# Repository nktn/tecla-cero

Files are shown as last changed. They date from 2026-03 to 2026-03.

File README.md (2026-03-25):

# TECLA-CERO(セロ)
シンプルなロータス配列の乾電池・トラボ付き無線分割キーボードです。
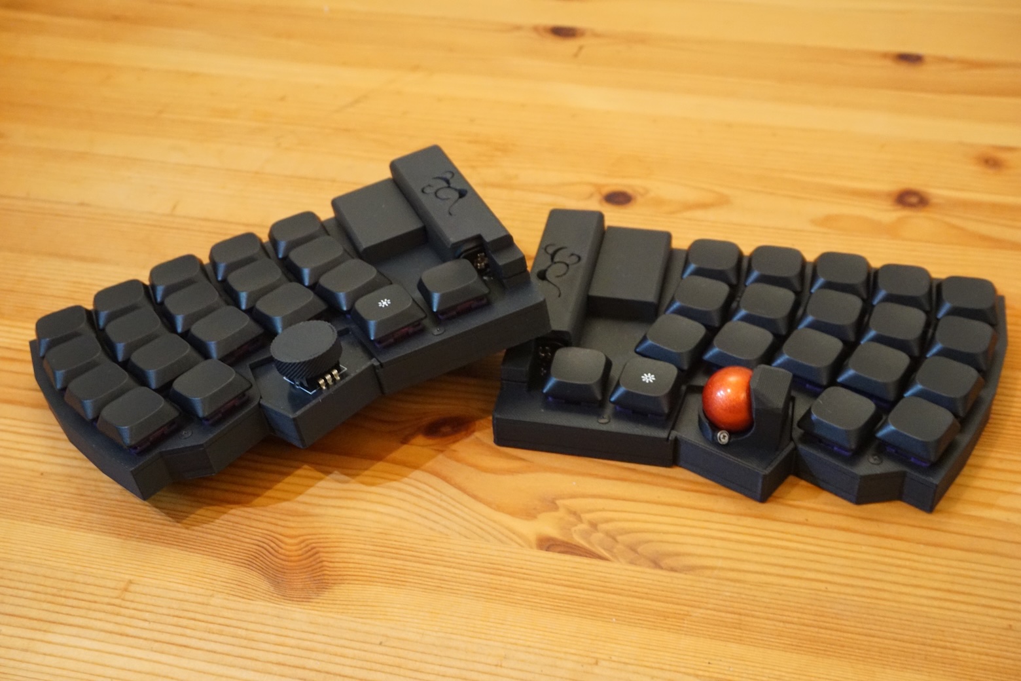
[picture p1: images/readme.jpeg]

## 特徴
- ロータス配列
- 38キー
- 左側にロータリーエンコーダー
- 右側にトラックボール（PAW3222）
- BMP Boost使用
- BLE/USB両対応
- keymap-editor / ZMK Studio対応 

## ビルドガイド
- [こちら](https://github.com/nktn/tecla-cero/blob/main/docs/buildguide_proto.md)を参考に進めてください

## 注意
- ソケット、ロータリーエンコーダー、電池ボックスのはんだ付けが必要です。
- ケースが3Dプリントでの確認しかできておりません

## 謝辞
本プロジェクトの設計は[torabo-tsuki-lp](https://github.com/sekigon-gonnoc/torabo-tsuki-lp) を参考にさせていただきました。

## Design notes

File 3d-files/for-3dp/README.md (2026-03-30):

# TECLA-CERO(セロ)の３Dプリント印刷設定例
キーケット2026に展示していたキーボードを作る際に設定したプリント設定を参考情報として記載させていただきます。

# 3Dプリントの機種
BambuLab A1 mini

# ビルドプレート
* テクスチャPEIプレート（A1 mini購入時のもの）
* (ノブ/トラックボールケース) スムースPEIビルドプレート

# フィラメント
PLA Matte(Black)

# Bambu Studio設定
バージョン：2.5.0.66  
システムプリセット： 0.20mm Standard @BBL A1M  
フィラメント設定など：デフォルト(変更なし)

# Stepファイルの読み込み設定
デフォルト  
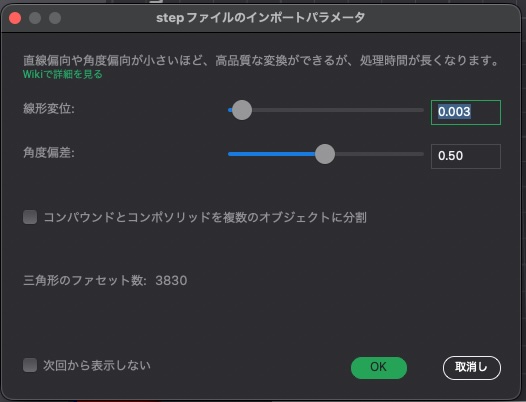
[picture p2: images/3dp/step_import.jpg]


# 各種設定について
左右に関して基本的には同じ設定をしています。(そして試行錯誤していたので1プレート1オブジェクトで印刷しておりました・・・ので印刷される際には複数配置などしてください)

## サポート有効化（パラメータはデフォルト）の設定
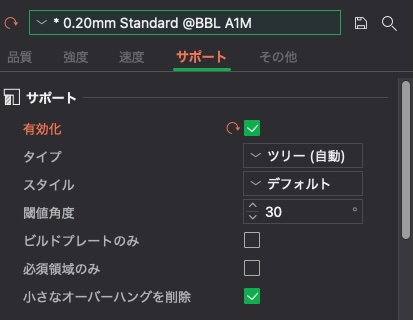
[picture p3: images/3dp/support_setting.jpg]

# Topプレート
サポート：有効化（パラメータはデフォルト）  
配置向き：マグネットを入れる口が上向きになるように配置してください。  
備考：今回は反ることがなかったのでブリムはつけておりません。必要に応じてセットしてください。
## 配置
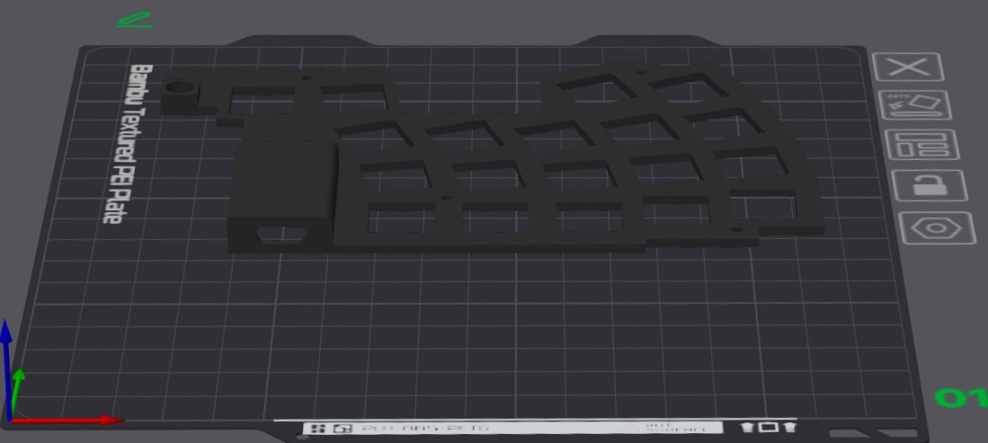
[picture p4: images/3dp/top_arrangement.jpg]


# 電池ケース
サポート：有効化（パラメータはデフォルト）  
配置向き：マグネットを入れる口が下向きになるように配置してください  
サポート編集：薄い部分と底面から離れている部分にサポートが有効になるように色付けしてください（私のは適当でちょっと恥ずかしいのですが。。。）

## 配置
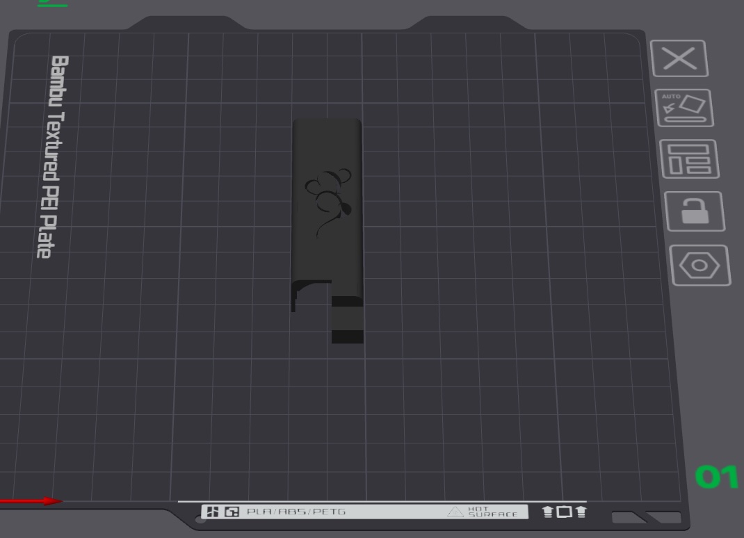
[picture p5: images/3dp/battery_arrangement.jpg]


## サポート編集：薄い部分
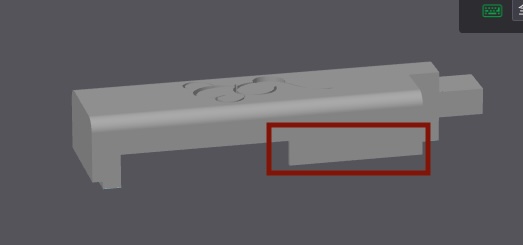
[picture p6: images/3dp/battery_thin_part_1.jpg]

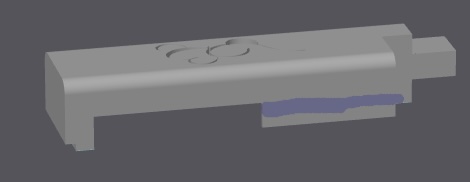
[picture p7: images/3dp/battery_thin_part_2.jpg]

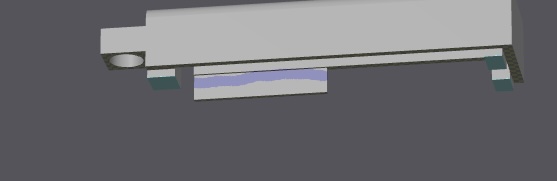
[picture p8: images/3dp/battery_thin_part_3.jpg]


## サポート編集：底面から離れている部分
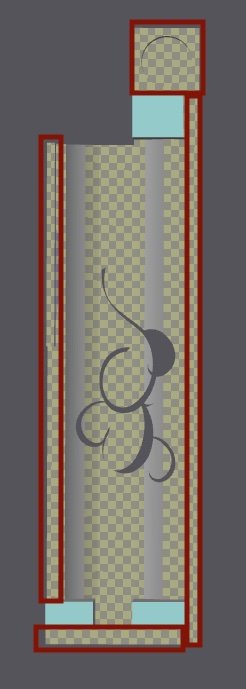
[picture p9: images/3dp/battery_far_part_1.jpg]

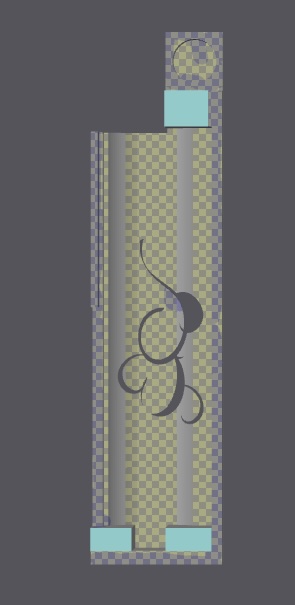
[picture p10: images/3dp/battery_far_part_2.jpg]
   
※わかりにくいですが薄い紫色がついているところです

## プレビュー
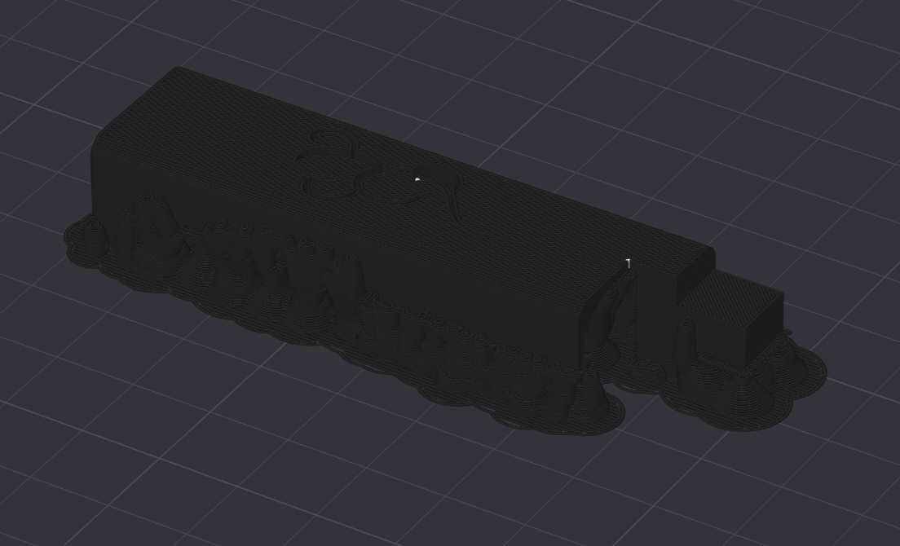
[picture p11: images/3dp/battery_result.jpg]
  

# ボトムケース
サポート：有効化（ブリムの関係？自動的についている）  
配置向き：底面が下になるように配置してください。  
マウス耳型ブリム：角全てに設定（親の仇かという感じで付けてました）  
ベッド接着：ブリムタイプ塗装済み  
備考：反ってしまう場合は洗濯ノリを使ってプリントするといいですよと聞きましてご自身の責任でお試しください。[参考記事](https://note.com/jinsato_tech/n/n6989bb54e91c)

## 配置
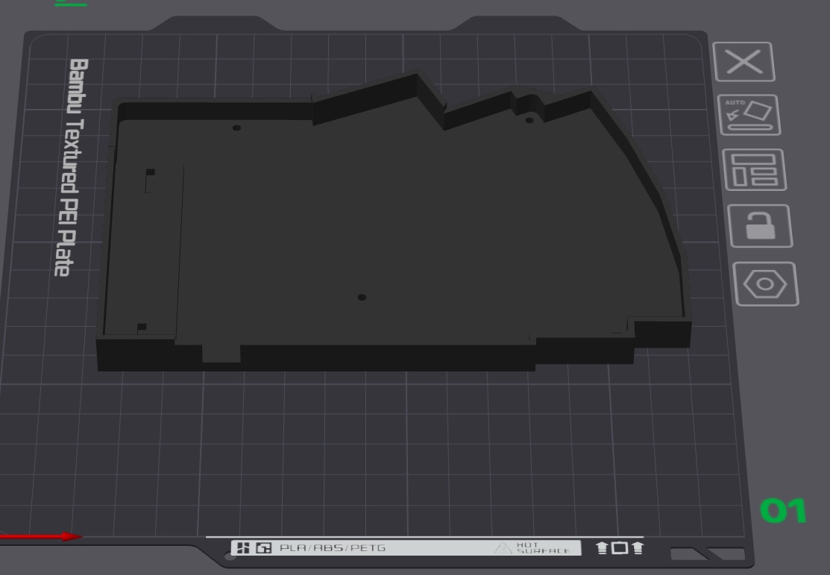
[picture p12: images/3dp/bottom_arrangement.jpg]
  

## ブリム
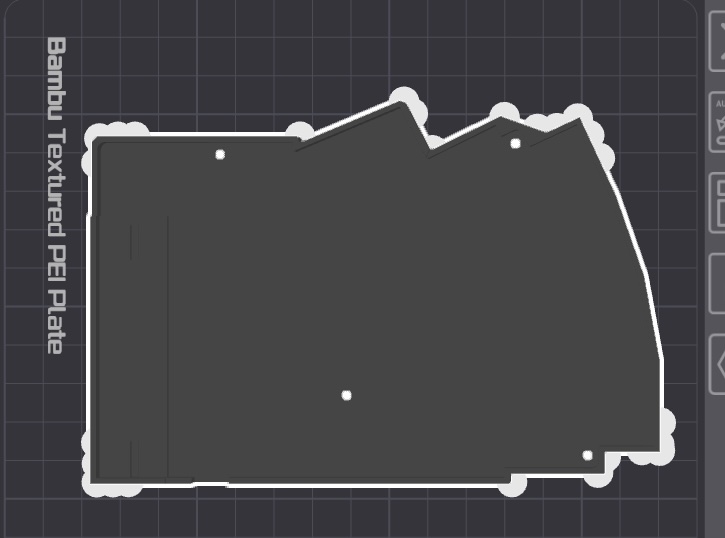
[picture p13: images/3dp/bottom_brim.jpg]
  

### ブリム設定
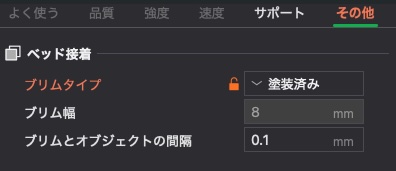
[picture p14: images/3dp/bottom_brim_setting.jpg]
 

## プレビュー
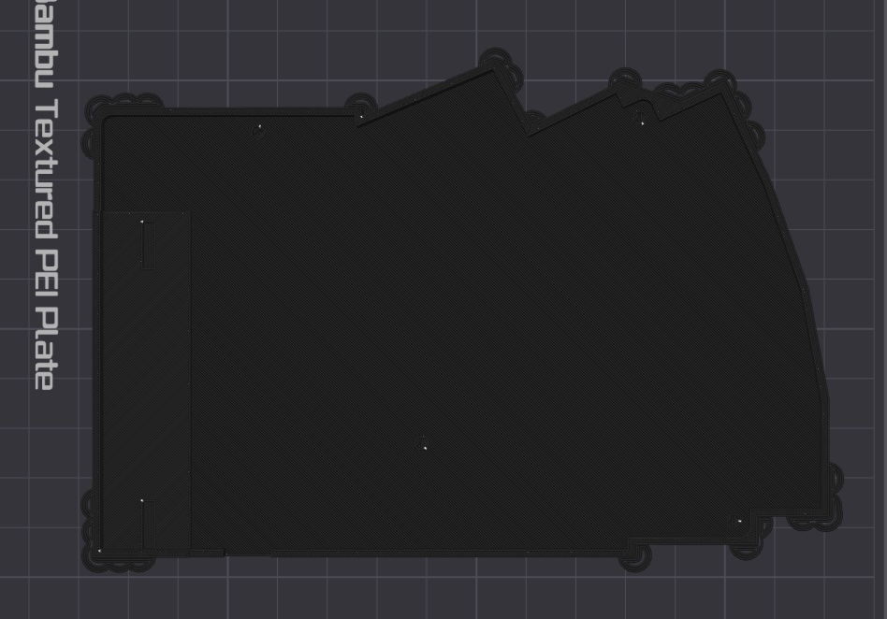
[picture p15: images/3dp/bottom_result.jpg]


# ノブ
配置向き：ノブに刺す穴を上になるように配置してください

## 配置
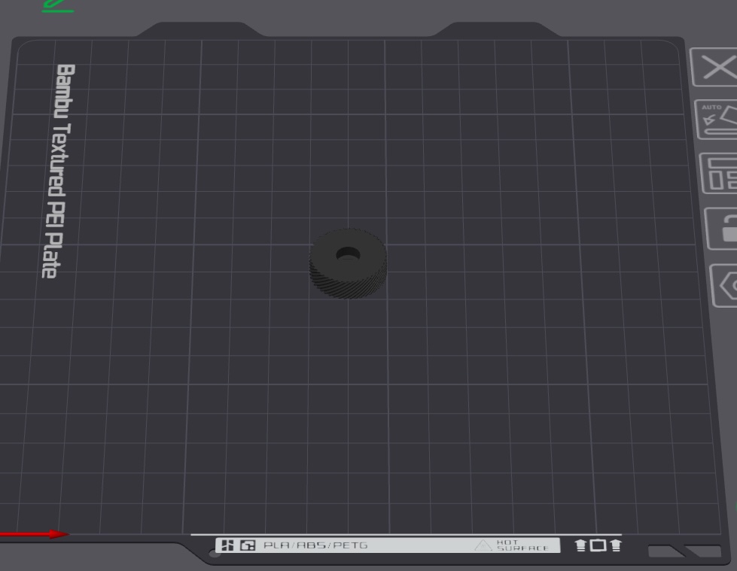
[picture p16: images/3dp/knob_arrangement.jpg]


# 一体型トラックボールケース
サポート：有効化（パラメータはデフォルト）  
配置向き：トラックボールを奥側を上に配置してください  
座標：Zを8度回転
## 配置
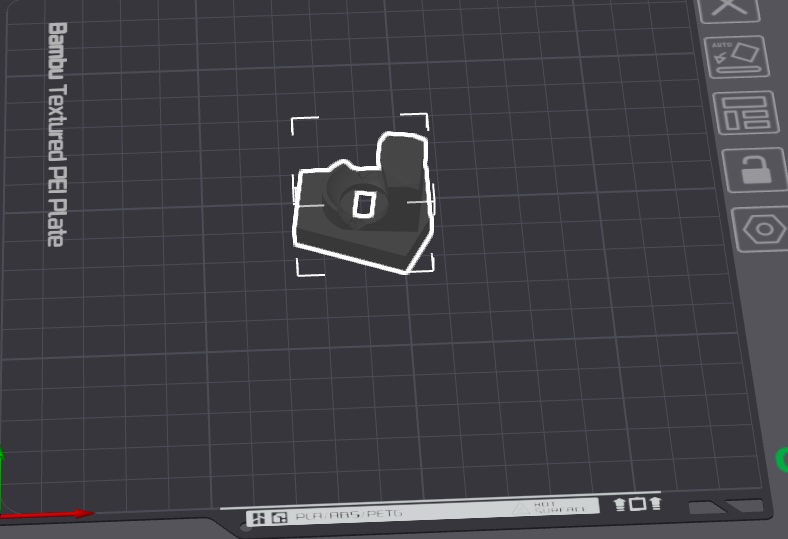
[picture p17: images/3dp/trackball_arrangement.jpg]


## 座標
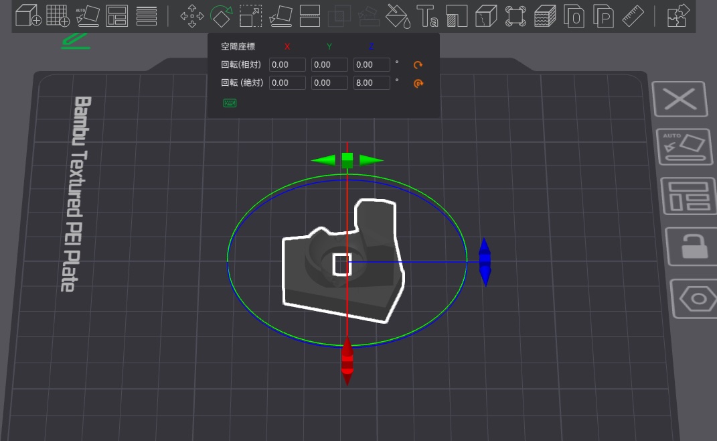
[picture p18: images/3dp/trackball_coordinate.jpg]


## プレビュー
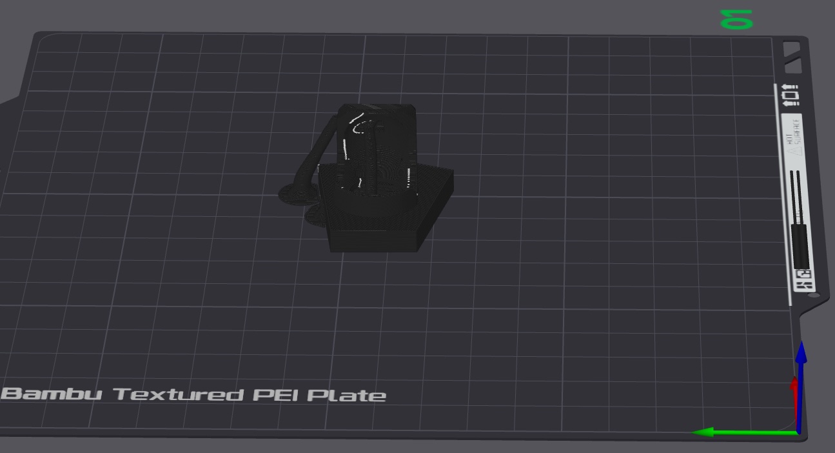
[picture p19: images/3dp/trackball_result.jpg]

※わかりにくいですがサポートが設定されている状態

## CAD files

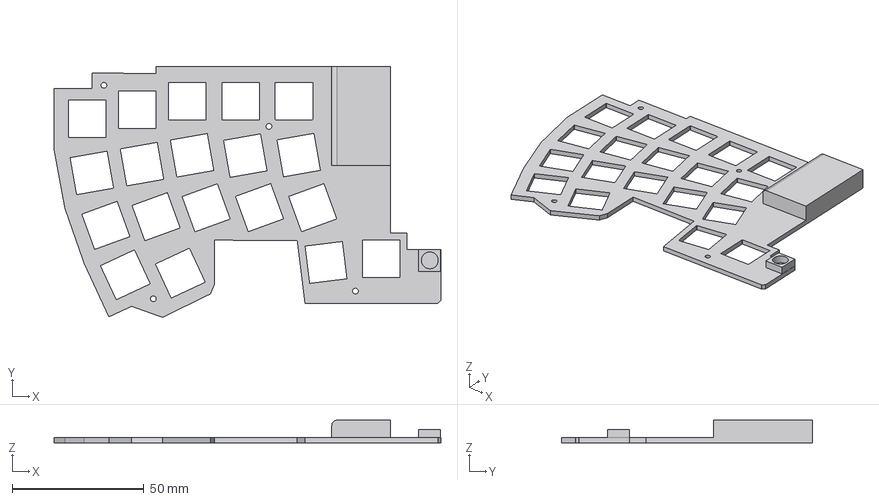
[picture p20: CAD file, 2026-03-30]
3d-files/for-3dp/left_top.step
146.7 x 95.1 x 8.60 mm
case-19mm-3-Body.step
フォルダー 18
acanthus_tall_bigleaf
left-B_Mask
right-User_Drawings
right-Edge_Cuts
left-Edge_Cuts_v2
mesh_large
mesh_for_shapr3d
controller-cover-aa-Body.step
left-F_Mask
left-B_Silkscreen
left-Edge_Cuts
left-F_Silkscreen
left-User_1

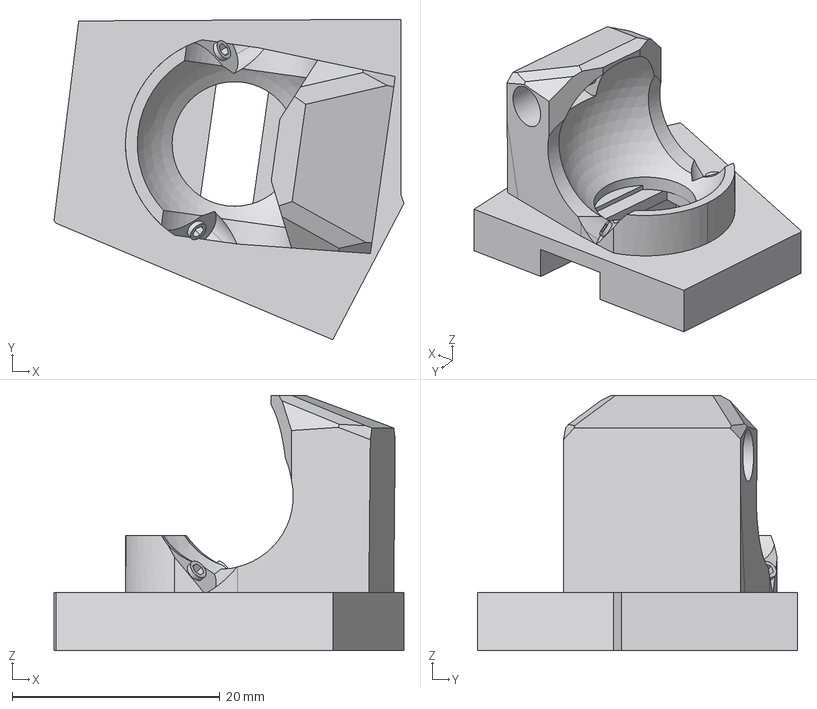
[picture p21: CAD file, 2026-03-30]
3d-files/for-3dp/right_trackball_case.step
33.7 x 30.9 x 24.6 mm
case-19mm-3-Body.step
フォルダー 18
acanthus_tall_bigleaf
left-B_Mask
right-User_Drawings
right-Edge_Cuts
left-Edge_Cuts_v2
mesh_large
mesh_for_shapr3d
controller-cover-aa-Body.step
left-F_Mask
left-B_Silkscreen
left-Edge_Cuts
left-F_Silkscreen
left-User_1

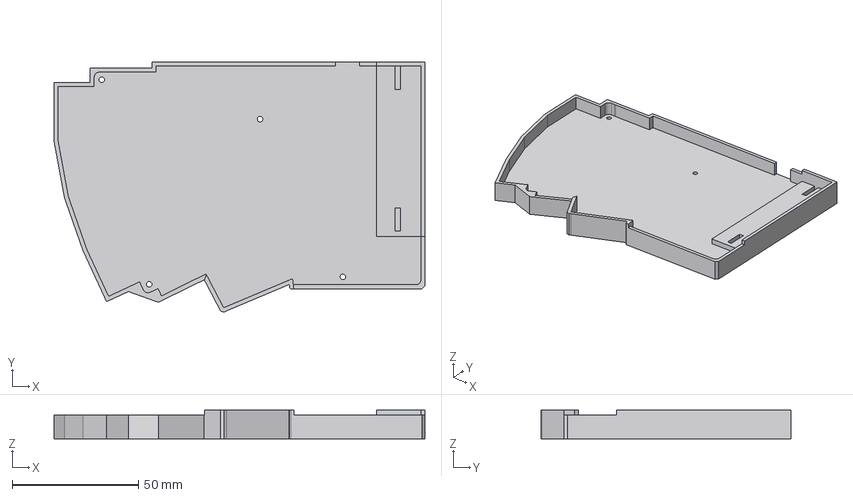
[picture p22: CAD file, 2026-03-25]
3d-files/for-3dp/left_bottom.step
146.8 x 99.0 x 11.4 mm
case-19mm-3-Body.step
left-B_Mask
right-User_Drawings
right-Edge_Cuts
left-Edge_Cuts_v2
mesh_large
mesh_for_shapr3d
controller-cover-aa-Body.step
left-F_Mask
left-B_Silkscreen
left-Edge_Cuts
left-F_Silkscreen
left-User_1

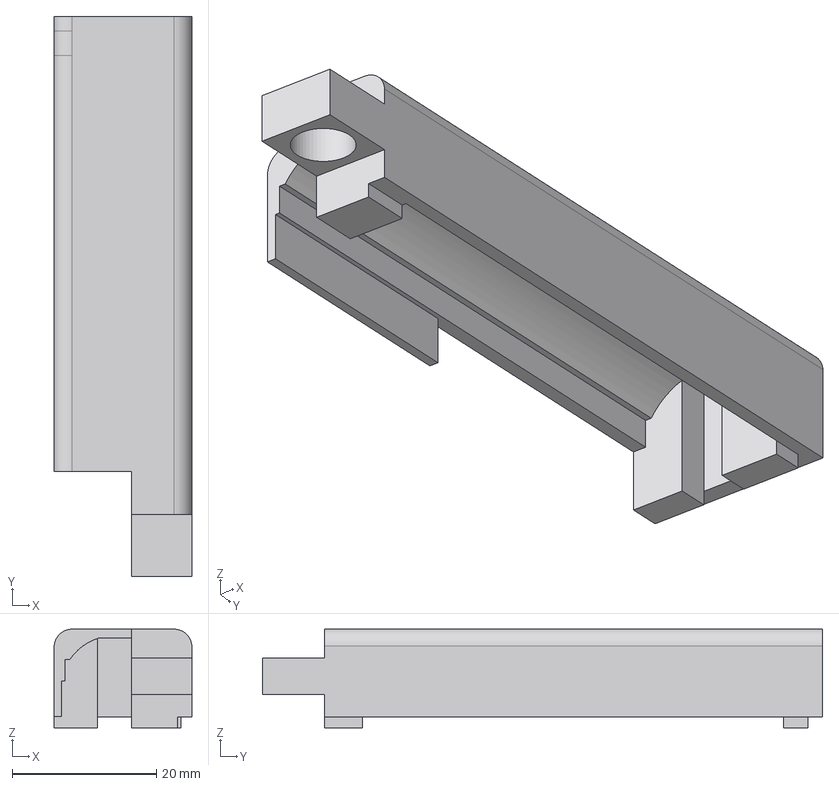
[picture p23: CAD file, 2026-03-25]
3d-files/for-3dp/left_battery_case.step
19.1 x 77.7 x 13.7 mm
case-19mm-3-Body.step
left-B_Mask
right-User_Drawings
right-Edge_Cuts
left-Edge_Cuts_v2
mesh_large
mesh_for_shapr3d
controller-cover-aa-Body.step
left-F_Mask
left-B_Silkscreen
left-Edge_Cuts
left-F_Silkscreen
left-User_1

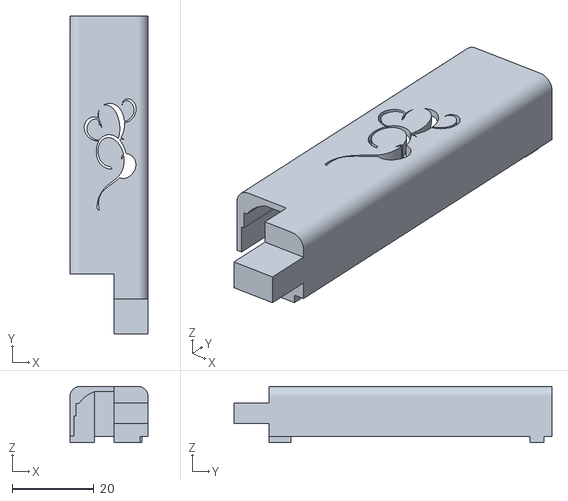
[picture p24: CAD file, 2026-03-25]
3d-files/for-3dp/left_battery_designed_case.stl
19.1 x 77.7 x 13.7

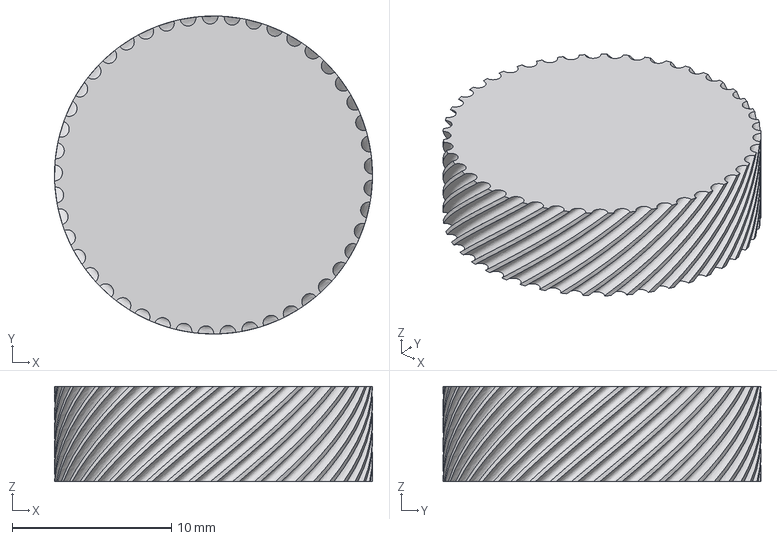
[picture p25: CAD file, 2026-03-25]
3d-files/for-3dp/left_knob.step
20.0 x 20.0 x 6.00 mm

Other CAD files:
3d-files/for-3dp/right_top.step
3d-files/for-3dp/right_battery_designed_case.stl
3d-files/for-3dp/right_battery_case.step
3d-files/for-3dp/right_bottom.step

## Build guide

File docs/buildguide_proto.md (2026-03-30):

# Build Guide for TECLA-CERO

こちらはTECLA-CEROのビルドガイドです。  
**はんだ付けが必要です**

また、プロトタイプということでケースが**3Dプリンターでの印刷**確認しかできておりません。

## プロト販売の同梱品
| 名称 | 数  |備考| 
|:-|:-|:-|
| プロトタイプメイン基板(PCBAで半組み立て済み) | 1 | プロト版として部品番号がプリントされたデザインです　|
| 電池ボックス(単三) | 2 |入手先：[秋月電子](https://akizukidenshi.com/catalog/g/g100308/)|
| スペーサー(6mm) | 8 |入手先：[遊舎工房](https://shop.yushakobo.jp/products/a0800c2?variant=37665435189409)|
| ねじ(M2x3.5) | 18  |入手先：[ウィルコ](https://wilco.jp/products/F/FX-EB.html#page3)|
| ロータリーエンコーダー (ロープロファイル) | 1  |入手先：[遊舎工房](https://shop.yushakobo.jp/products/2141?variant=37799941963937)|
| フレキシブルケーブル(0.5mmピッチ、6P、100mm、電極同一面) | 1 |トラックボール用部品 / Amazonなど|
| ベアリング(4x1.5x2 mm) | 3 |トラックボール用部品 / 入手先:[Amazon](https://www.amazon.co.jp/dp/B0CV75YFQY)|
| ねじ(M1.4) | 3 |トラックボール用部品 / 入手先:Amazonなど|
| (同梱はおまけ)19.05mm トラックボール | 1 |BOOTHやAliexpressなどありますが、 [BEEKEEBのオレンジレッド](https://shop.beekeeb.jp/products/19mm-trackball)がおすすめです（ダークグレイの動作も確認しています）。|
| キースイッチソケット(Choc V2) |38 | 入手先：[遊舎工房](https://shop.yushakobo.jp/products/a01ps?variant=37665172553889) など |

## 別途入手が必要な部品

| 名称 | 数  |備考|
|:-|:-|:-|
| BMP Boost | 2 | 入手先：[BOOTH](https://booth.pm/ja/items/1177319), [遊舎工房](https://shop.yushakobo.jp/products/10737) |
| トラックボールセンサー(14mmマウスセンサーモジュール) | 1 | 入手先：[BOOTH](https://nogikes.booth.pm/items/6520217)
| キースイッチ(Choc V2) |38 |配布の3dp版は静音スイッチが良いかと思います。|
| キーキャップ | 38  | 19mmのロープロファイル用のキーキャップ|
| コンスルー | 4 | 13ピン（高さ2.5mm）を使用してください。/ 入手先：[遊舎工房](https://shop.yushakobo.jp/products/31?variant=37665714438305) |
| 乾電池 | 2 | 単三、Ni-MH可。USBで充電できるリチウム電池内蔵のものを使う場合、必ずキーボードから取り外してから充電してください |
| 瞬間接着剤 | 1 | 入手先：[amazon](https://www.amazon.co.jp/dp/B009AO65NS) |
| ネオジムマグネット | 4 | 直径6mmのマグネット。入手先：[100均ショップ：キャンドゥなど](https://netshop.cando-web.co.jp/view/item/000000023967)|
ゴム足                                            | 8   |GRIPLUSのものがおすすめですが、お好きなものをご準備ください
| トッププレート(3dp版)                                           | 2   |[3df-files/for-3dpフォルダ](https://github.com/nktn/tecla-cero/tree/main/3d-files/for-3dp)のファイルを３Dプリンターで印刷してください|
| ボトムプレート(3dp版)                                             | 2   |[3df-files/for-3dpフォルダ](https://github.com/nktn/tecla-cero/tree/main/3d-files/for-3dp)のファイルを３Dプリンターで印刷してください|
| 電池ケースカバー(3dp版)                                             | 2   |デザインありとなしの２種類あります。お好みで[3df-files/for-3dpフォルダ](https://github.com/nktn/tecla-cero/tree/main/3d-files/for-3dp)のファイルを３Dプリンターで印刷してください|
エンコンダーノブ(3dp版)                                             | 1   |[3df-files/for-3dpフォルダ](https://github.com/nktn/tecla-cero/tree/main/3d-files/for-3dp)のファイルを３Dプリンターで印刷してください|
トラックボールケース(3dp版)                                             | 1   |[3df-files/for-3dpフォルダ](https://github.com/nktn/tecla-cero/tree/main/3d-files/for-3dp)のファイルを３Dプリンターで印刷してください|

## 利用工具
- はんだごて
- はんだ
- ニッパー
- ペンチ
- ドライバー
- やすり
- PC
- USBケーブル

## 組立手順

### キースイッチソケットをメイン基板にはんだ付けする
左右のメイン基板にキースイッチソケットをはんだ付けしていく。
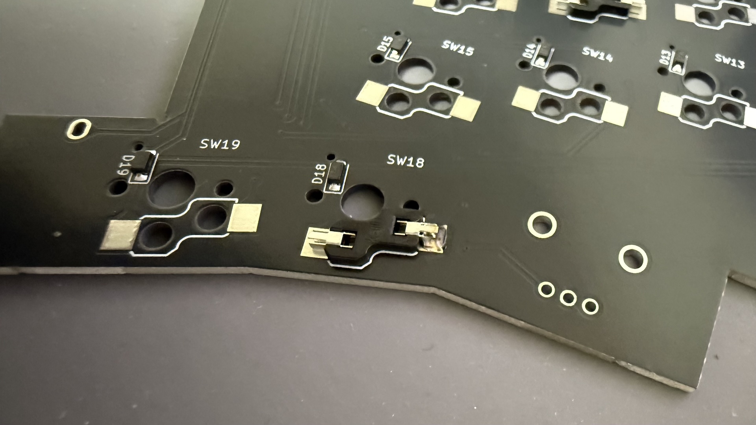
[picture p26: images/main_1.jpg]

### ロータリーエンコーダーを左側のメイン基板にはんだ付けする
左のメイン基板の裏面に3箇所はんだ付けをしていきます。
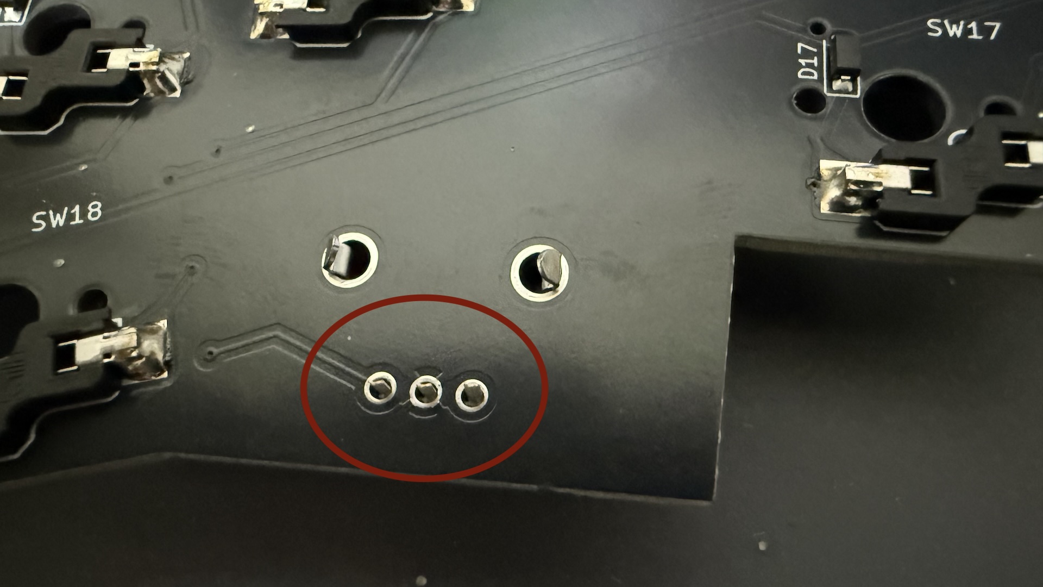
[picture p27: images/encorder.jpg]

### 電池ボックスをメイン基板にはんだ付けする
1. 電池ボックスの足を折り曲げる。
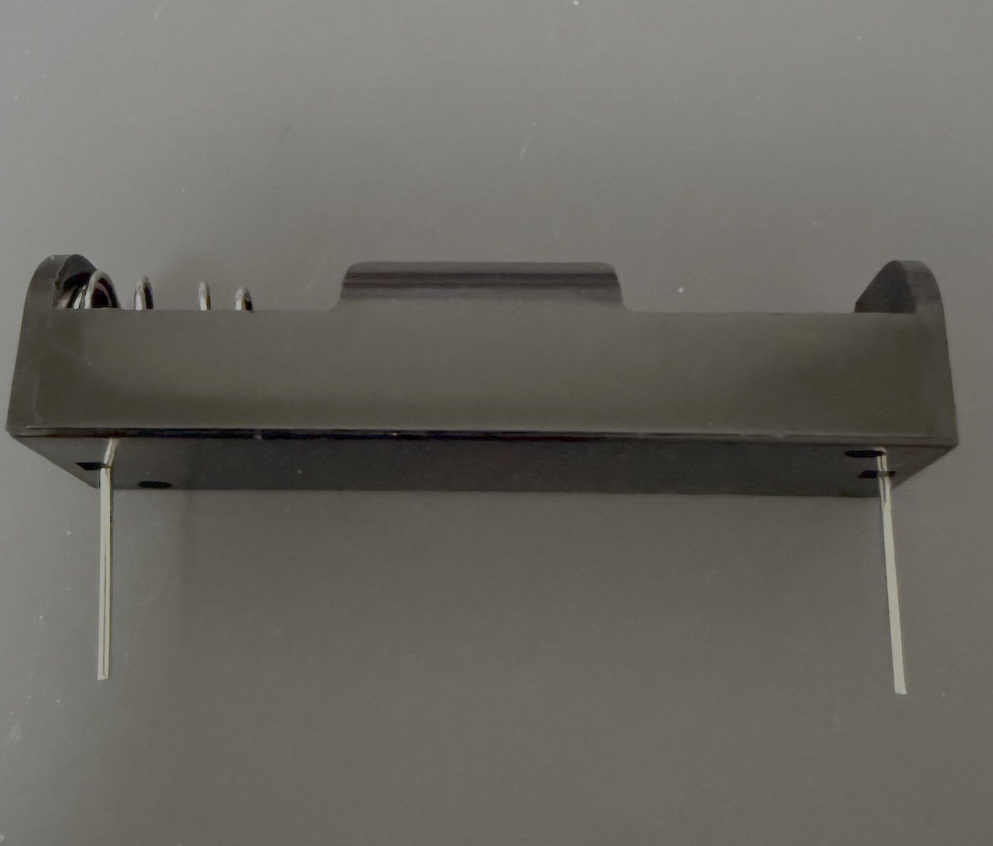
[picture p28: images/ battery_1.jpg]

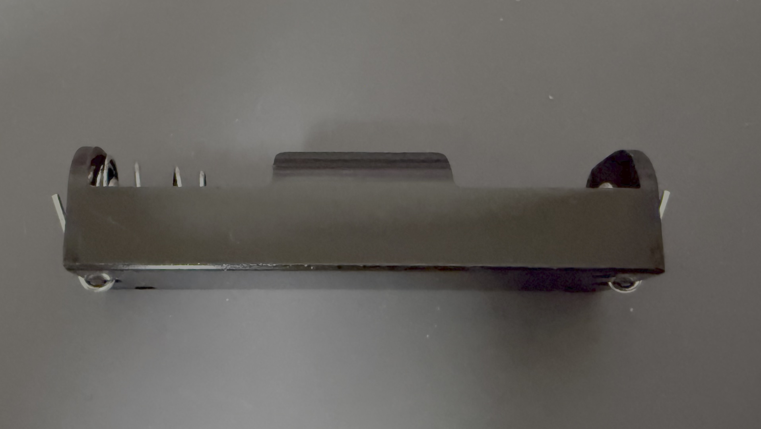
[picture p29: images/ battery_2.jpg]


2. プラスやマイナスの向きに気をつけてメイン基板を載せ、余った足を短く切ってはんだ付けをする。
※プラス側・マイナス側両方ともハンダ付けをしてください。
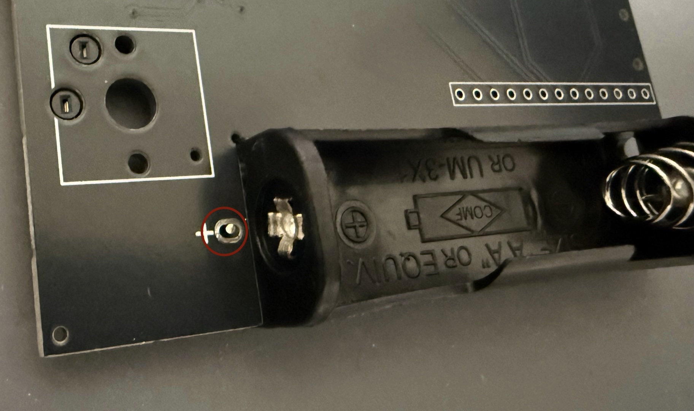
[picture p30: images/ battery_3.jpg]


ここではんだ付けは終わりです。

### メイン基板にBMP Boostをコンスルーで取り付ける
左右のメイン基板につけます。はんだ付けは不要です。  
※必ずコンスルーの向きは揃えてください。
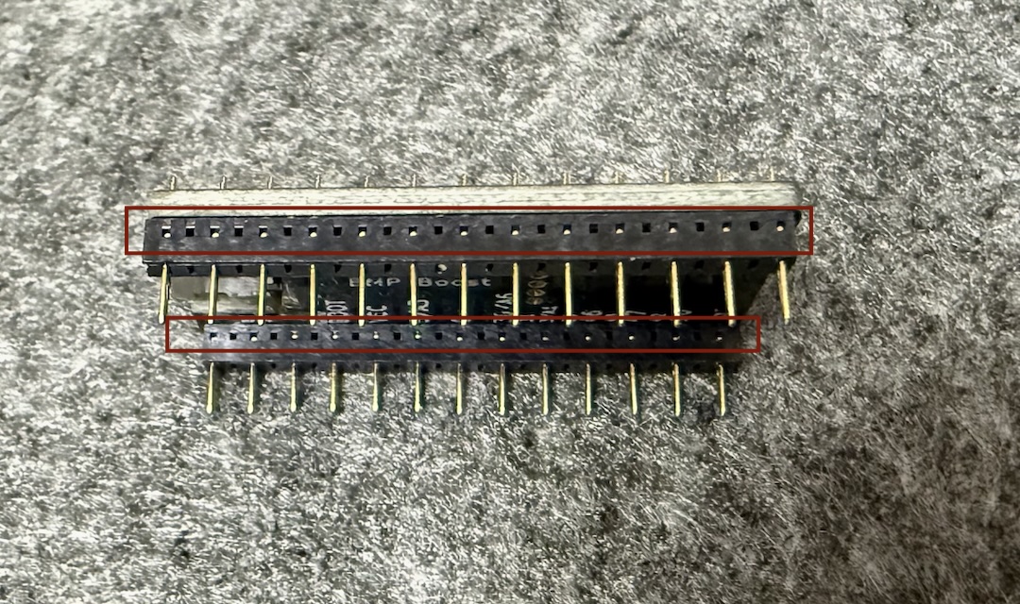
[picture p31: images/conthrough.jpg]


### トッププレート・メイン基板にスイッチを差し込む
メイン基板にトッププレートを重ねてスイッチを差し込んでください。
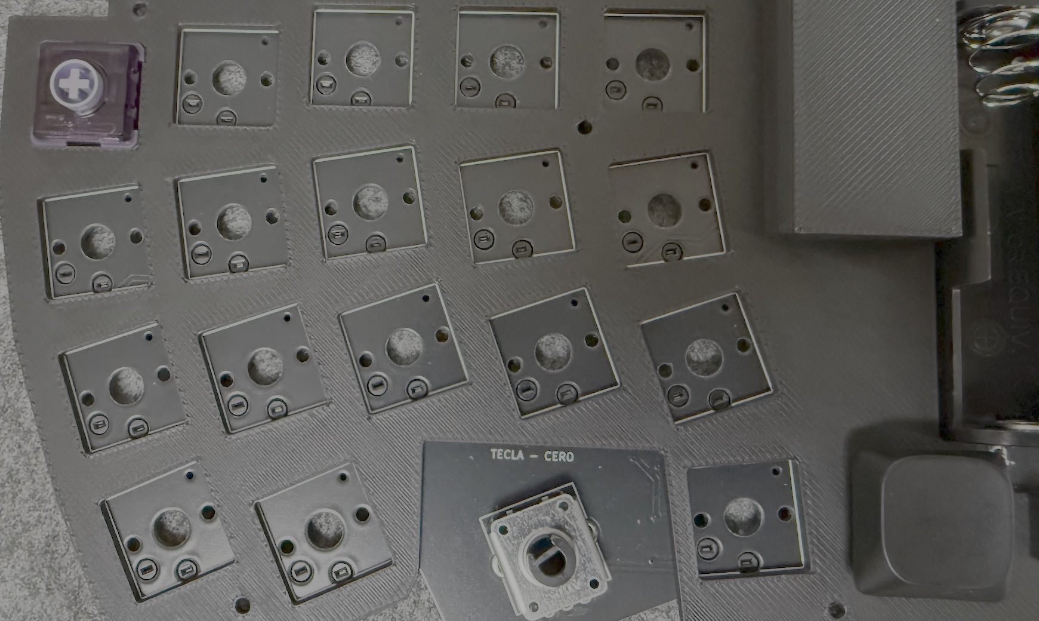
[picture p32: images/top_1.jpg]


ロータリーエンコーダーにノブをつけてください。
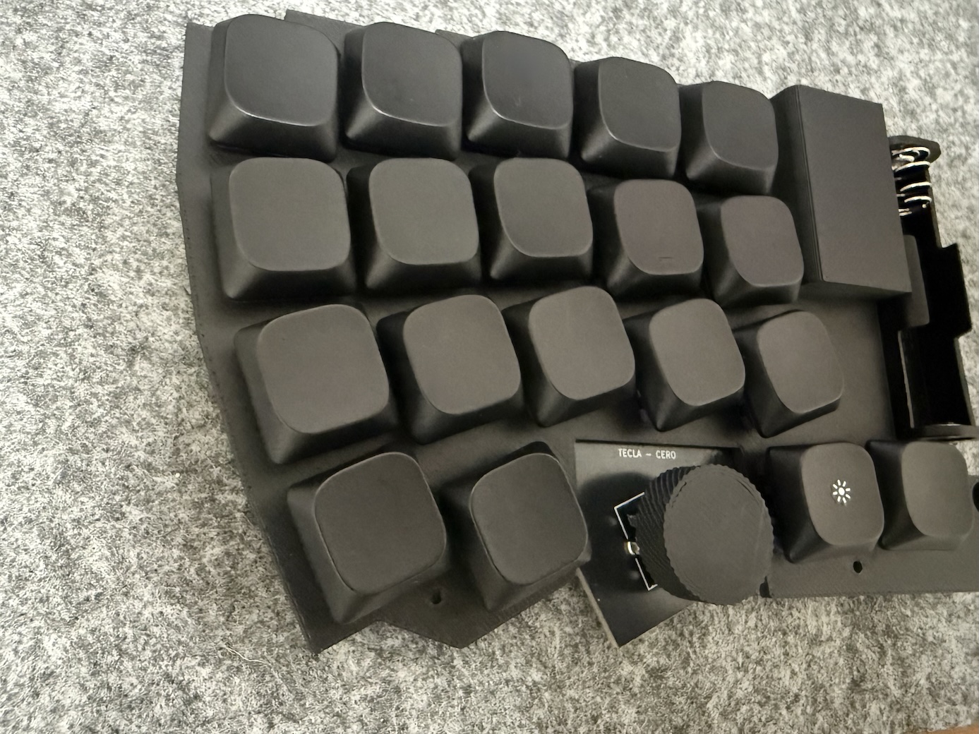
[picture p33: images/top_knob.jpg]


### トッププレートにスペーサーをねじ止めする
左右両方に4箇所ずつねじ止めしてください。
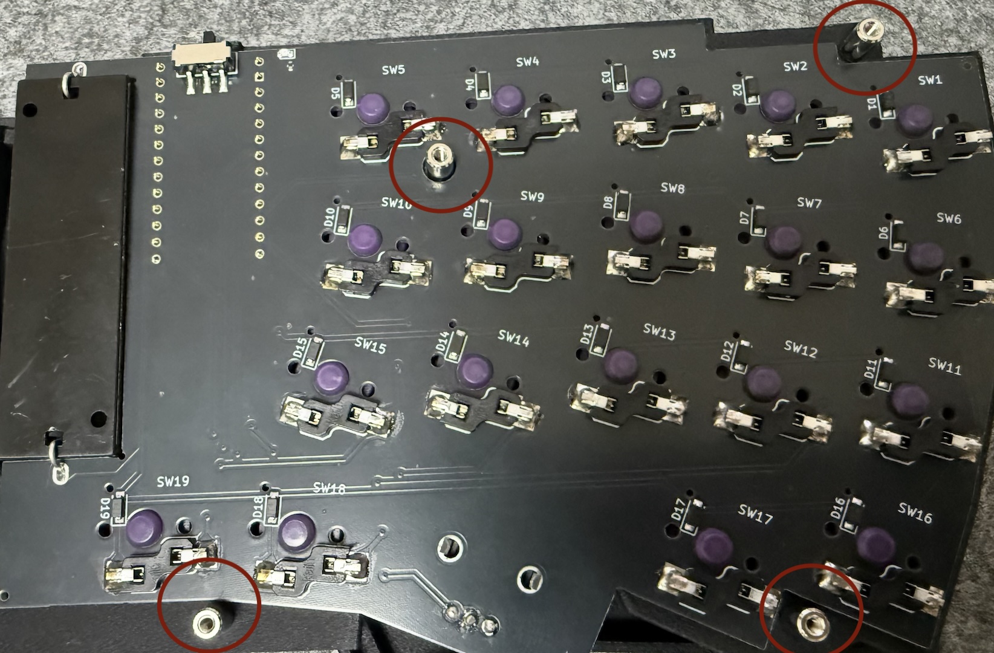
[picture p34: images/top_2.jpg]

### ファームウェアを書きこむ
1. スイッチをOFFにした状態で、BMPをPCにUSBケーブルで接続します。
2. BLEMICROPROという名前のストレージがマウントされたら、中身にINFO_UF2.TXTがあることを確認してください。
3. [Releases](https://github.com/nktn/zmk-keyboard-tecla-cero/releases)からファームウェアのuf2ファイルをダウンロードします。
4. uf2ファイルを1つ選んでストレージにコピーしてください。
トラックボールがある方をCentral、ない方がPeripheralが良いかと思います。（逆でも動くことを確認はしています）
※つまり右手にtecla_cero_right_central.uf2、左手にtecla_cero_left_peripheral.uf2を書き込んでください。
書き込みが完了したら一度USBケーブルを抜き、スイッチをONにした状態でUSBケーブルを差し直すとキーボードとして動作します。
### トラックボールケースにベアリングをネジで固定
穴にねじを押し込みながら回してベアリングを固定してください。
### トラックボールセンサーにケーブルを差し込む
コネクタの黒いのフラップを上に持ち上げ、トラックボールのケーブルをしっかり奥まで差し込み、フラップを下げてください。  
※右側に取り付けます。  
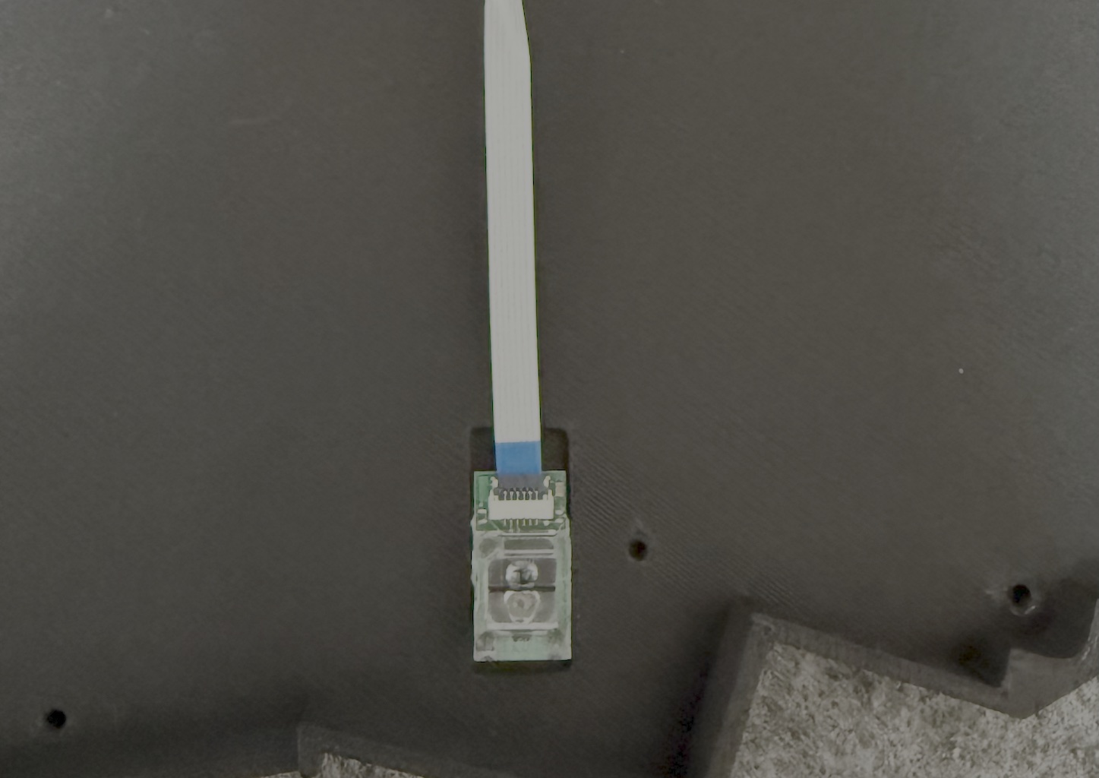
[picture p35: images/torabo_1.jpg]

### トラックボールのケーブルを右側のメイン基板のコネクタに差し込む
こちらも同様にケーブルを差し込み、フラップを下げてください。
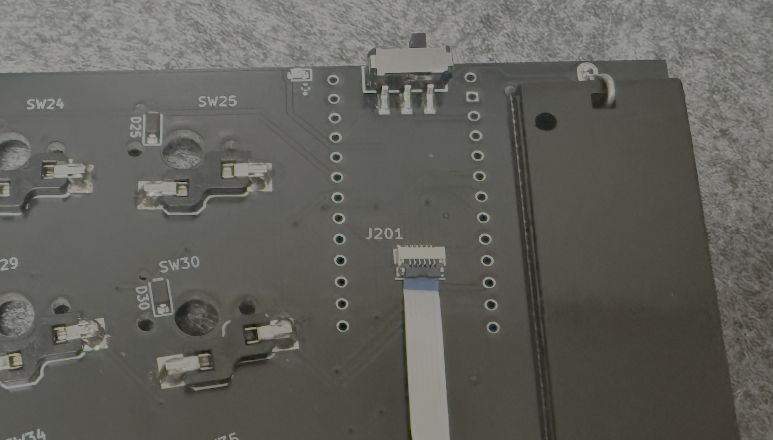
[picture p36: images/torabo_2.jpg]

### トラックボールセンサーの動作確認をする
USBケーブルでPCとBMP Boostを接続してレンズの上空を指で動かしたりしてマウスカーソルが動くか確認してください。
センサーの動作確認ができたらUSBケーブルは取り外してください。
### トラックボールセンサーを右側のボトムプレートに取り付ける
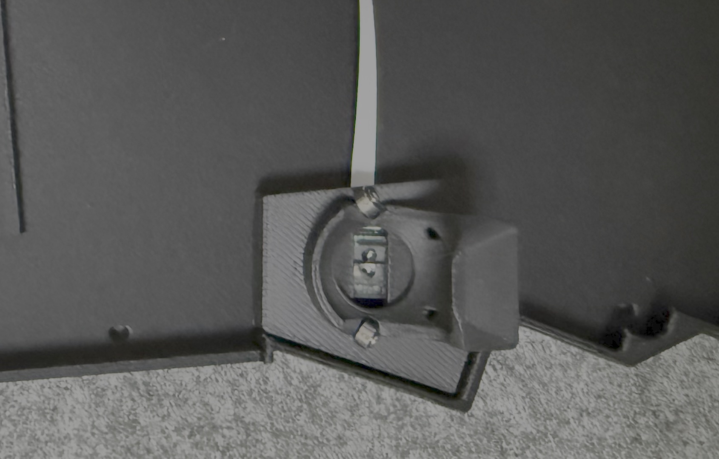
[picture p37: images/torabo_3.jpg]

裏から2箇所ねじ止めをしてください。
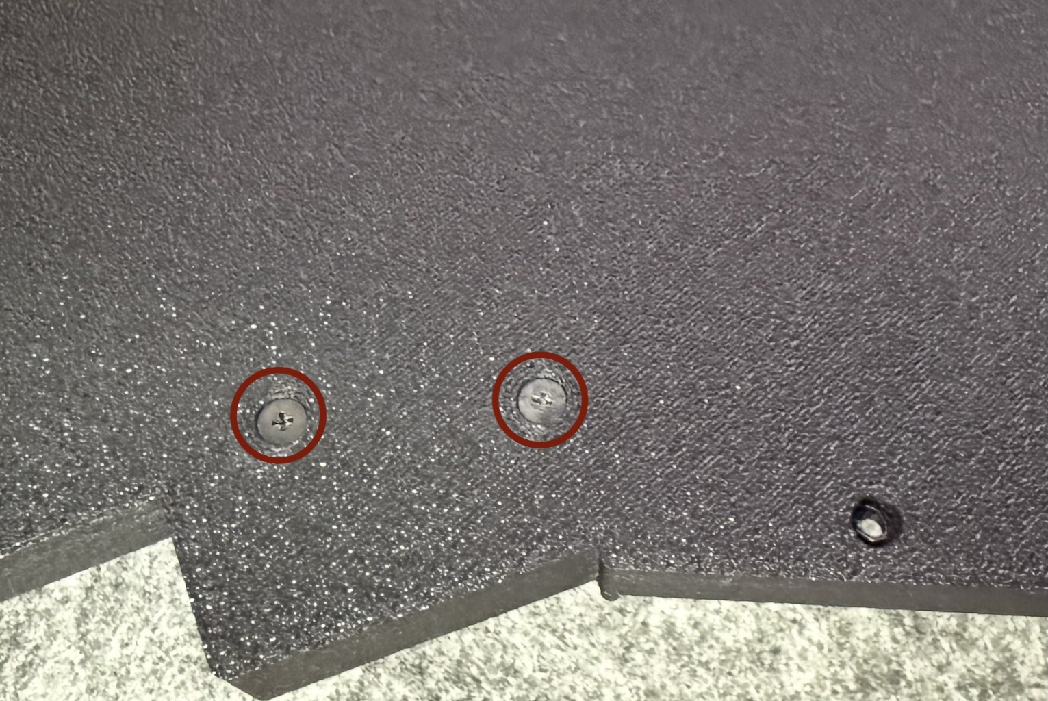
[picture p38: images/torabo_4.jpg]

### ボトムプレートの取り付けとゴム足をつける。
トッププレートとボトムプレートを重ねて裏側のねじを止めて完成です。(※写真は左側のものです。左右とも取り付けてください)
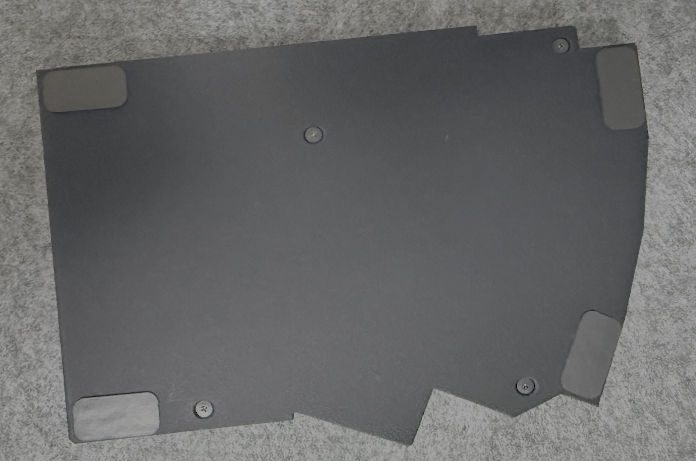
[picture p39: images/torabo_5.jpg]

### 磁石をトッププレートに嵌め込む
※瞬間接着剤の取り扱いに気をつけてください。
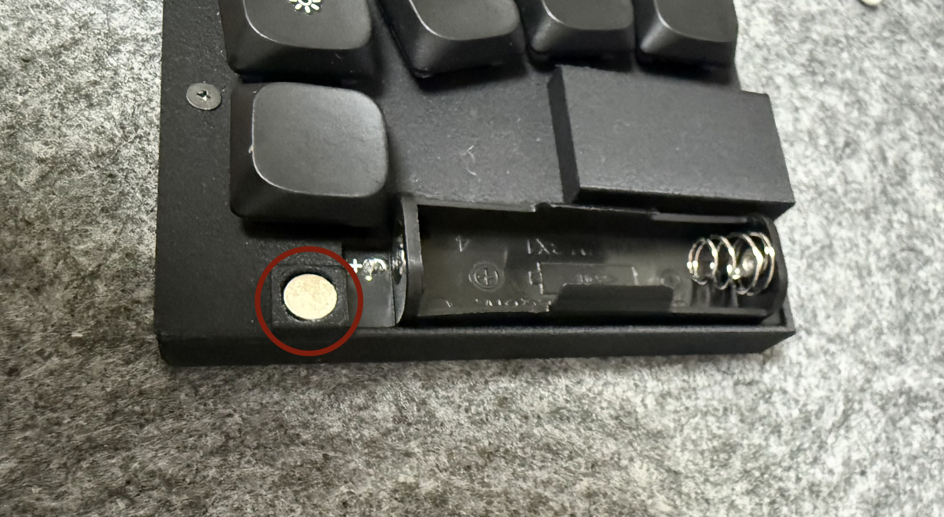
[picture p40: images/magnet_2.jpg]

### 磁石を電池ケースを嵌め込む
※瞬間接着剤の取り扱いに気をつけてください。
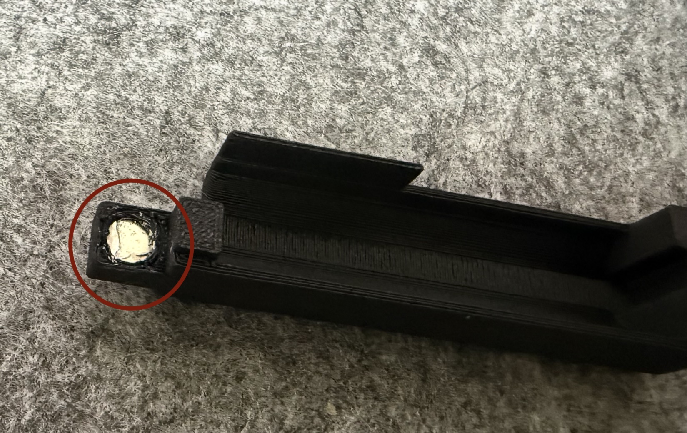
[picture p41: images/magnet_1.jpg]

電池ケースをトッププレートに重ねたら完成です。  
現時点の電池ケースは被せて磁石でとめている感じになります
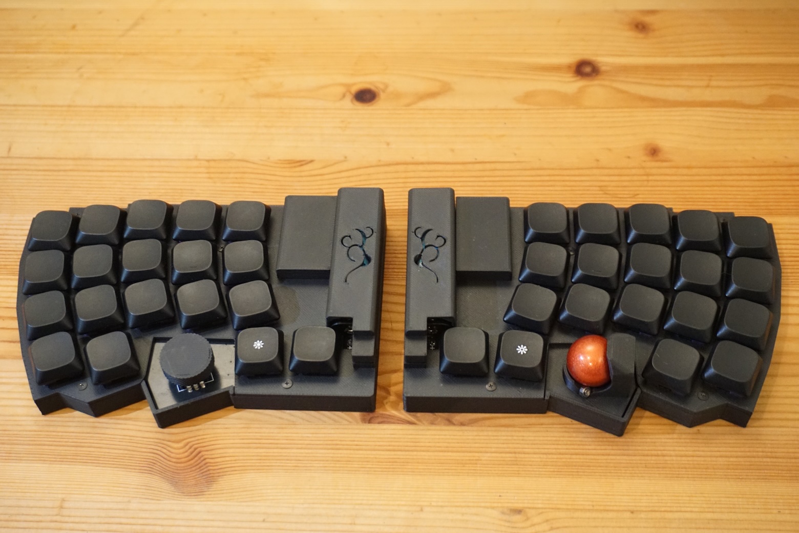
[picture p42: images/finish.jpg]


## 使い方

### 電源の説明
スライドスイッチをON側に切り替えると電源が入ります。電源がONするとLEDが点滅します。

### LEDの説明
BMP Boostの付近に赤色LEDがついています。
試験的に作ったケースのため電源スライドスイッチの穴から光を確認してください。
### 無線接続
両手の電源スライドスイッチをONして、接続先のデバイスでペアリングします。

### キーマップを変更する

* [ZMK Studio](https://zmk.studio/)または[Keymap-Editor](https://nickcoutsos.github.io/keymap-editor/)でキーマップが変更できます。
* Keymap-Editorを使用する場合は[zmk-keyboard-tecla-cero](https://github.com/nktn/zmk-keyboard-tecla-cero)をクローンして編集してください。
  * [ファームウェアの書き込み方](#ファームウェアを書きこむ)同様に、新しく作ったuf2ファイルを書き込んでください。

## トラブルと対策

* 初期不良による部品交換が必要な場合や、組立ミスで一部購入したい場合は[XからDMメッセージ](https://x.com/milio_kbd)をお送りください(booth専用ページを案内します)
* 組立にあたってのトラブルで相談がある場合は本リポジトリのissueに投稿してください。
* (磁石側の方が印刷によって低くなってしまい)電池ケースの前側が浮いてくる時は、電池ケースの磁石の下側に滑り止めシール(厚み1mmくらいのもの:写真のものはGRIPLUSのものをカットして貼った例です)を貼ると安定します
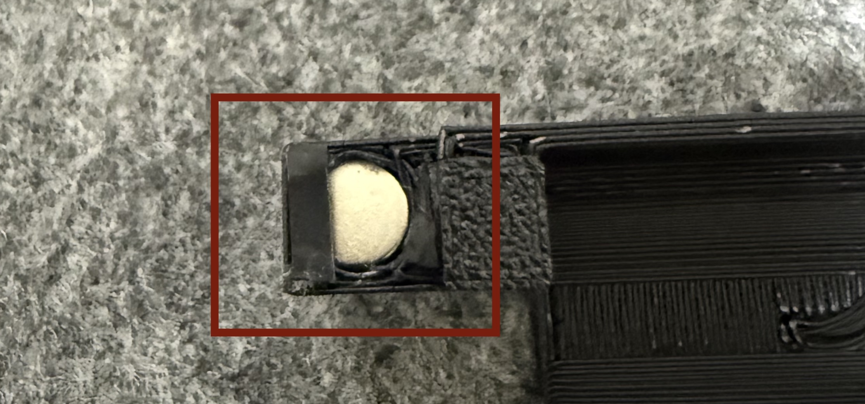
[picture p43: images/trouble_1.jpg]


* 煙が出たり異常な状態になりましたら、使用を中止して電源を切り電池を抜いてください。
* 長期間使用しない場合は電池を取り出してください。

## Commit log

2026-03-25 first commit
    Includes sanitize script and pre-commit hook for STEP file headers.
    [left_battery_case.step, left_battery_designed_case.stl, left_bottom.step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]
2026-03-30 update 3dfiles
    [left_top.step, right_trackball_case.step]
2026-03-30 3dプリント設定例の追加
2026-03-30 stepファイルのインポートのキャプチャの追加
